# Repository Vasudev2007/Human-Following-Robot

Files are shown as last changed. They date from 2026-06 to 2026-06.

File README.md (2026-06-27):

# Autonomous Human-Following Robot

This repository is a digitalization of the course project for **TA212 (Introduction to Manufacturing Process II)** under Professor Sarvesh Mishra, completed during the 2025 Odd semester at the Indian Institute of Technology Kanpur.

An Arduino-based autonomous robot capable of tracking and following a human target. It uses an ultrasonic sensor mounted on a servo motor to gauge distance, and two infrared (IR) sensors to detect directional movement and steer the chassis.

---

## 🏆 Awards & Recognition
This project, officially titled **"Human Tracker Bot,"** was awarded the **2nd Best Project** (Tuesday Batch, Gr. No. 10) in the TA-212 Lab.

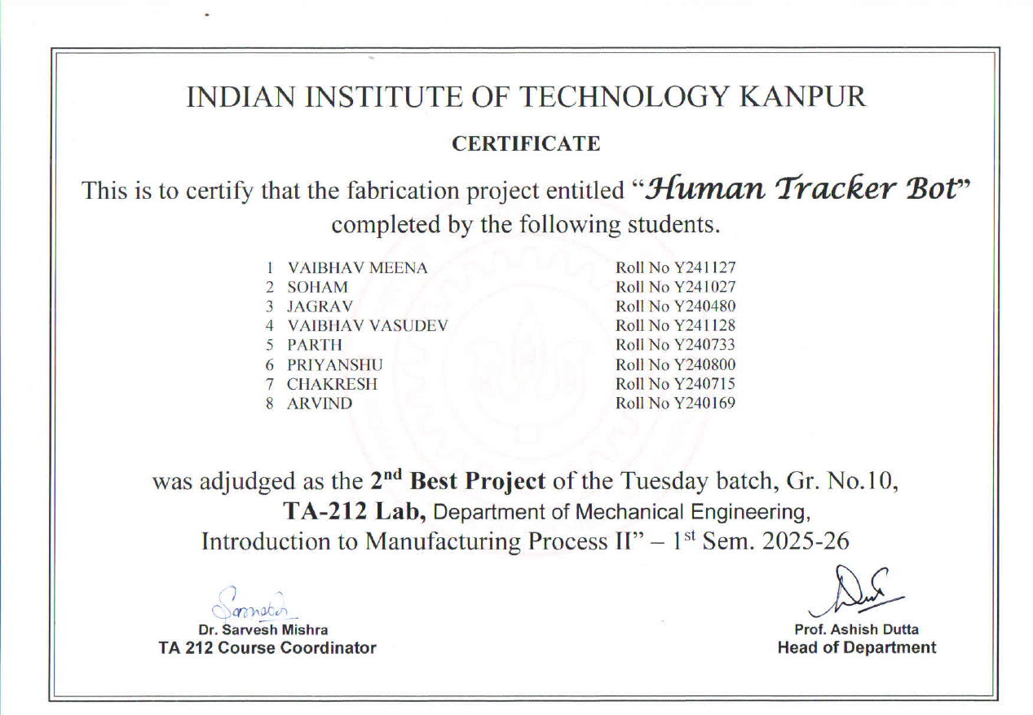
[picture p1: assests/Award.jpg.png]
TA212 2nd Best Project Certificate


---

## 🤝 Team Members
This robot was successfully fabricated and programmed through the collaborative efforts of:
* Vaibhav Meena
* Soham
* Jagrav
* Vaibhav Vasudev
* Parth
* Priyanshu
* Chakresh
* Arvind
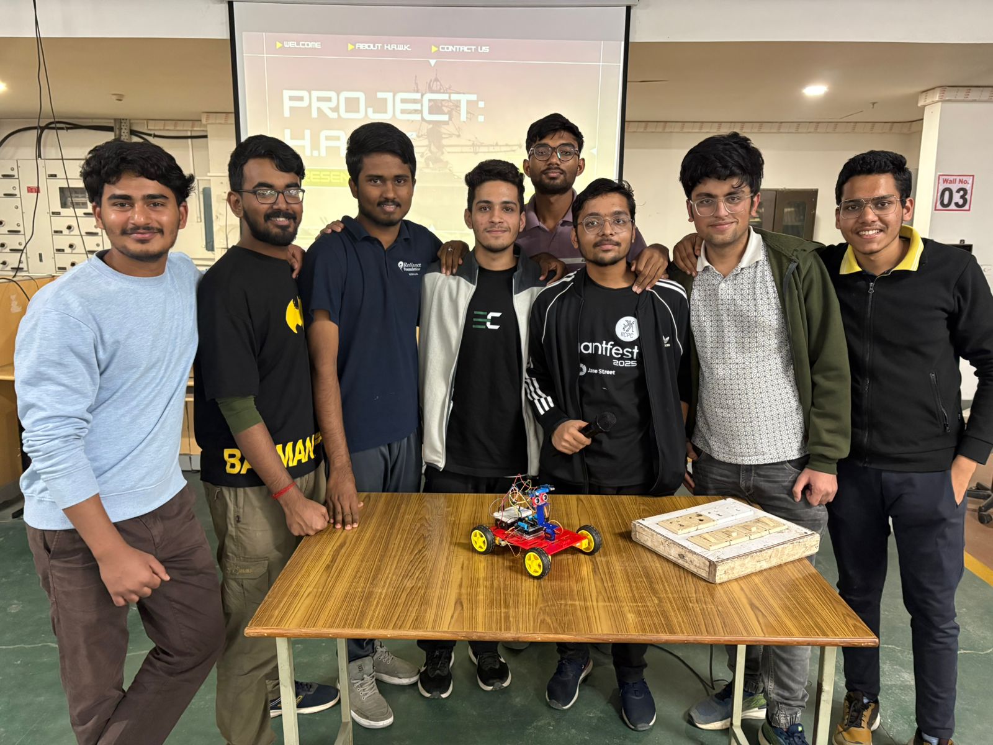
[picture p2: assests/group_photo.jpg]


---
## 🛒 Parts List & Purchase Links (Amazon.in)
1. [Arduino Uno](https://amzn.to/35flEXS)
2. [Motor Driver Shield](https://amzn.to/30Z9ijj)
3. [TT Gear Motor and wheels set](https://amzn.to/31WSD0Z)
4. [Servo Motor](https://amzn.to/2IAigNH)
5. [Ultrasonic Sensor](https://amzn.to/33fwrQa)
6. [18650 Li-on Battery (2x)](https://bit.ly/2CZabQ7)
7. [18650 Battery Holder](https://amzn.to/33iY4b3)
8. [Male and Female Jumper wire](https://amzn.to/2MmRjOE)
9. Acrylic Sheet - *(Offline Store)*
10. [DC Power Switch](https://bit.ly/2FtyEzs)

## 🛠️ Hardware Components
*   **Microcontroller:** Arduino Uno
*   **Motor Driver:** L293D Motor Driver Shield
*   **Motors:** 4x TT Gear Motors with Rubber Wheels
*   **Distance Sensor:** HC-SR04 Ultrasonic Sensor
*   **Directional Sensors:** 2x Infrared (IR) Obstacle Avoidance Sensors
*   **Actuator:** SG90 Micro Servo Motor
*   **Power:** 2x 18650 Li-ion Batteries & Battery Holder
*   **Chassis:** Custom/3D-printed base and acrylic brackets

---

## 🔌 Circuit & Wiring Connections
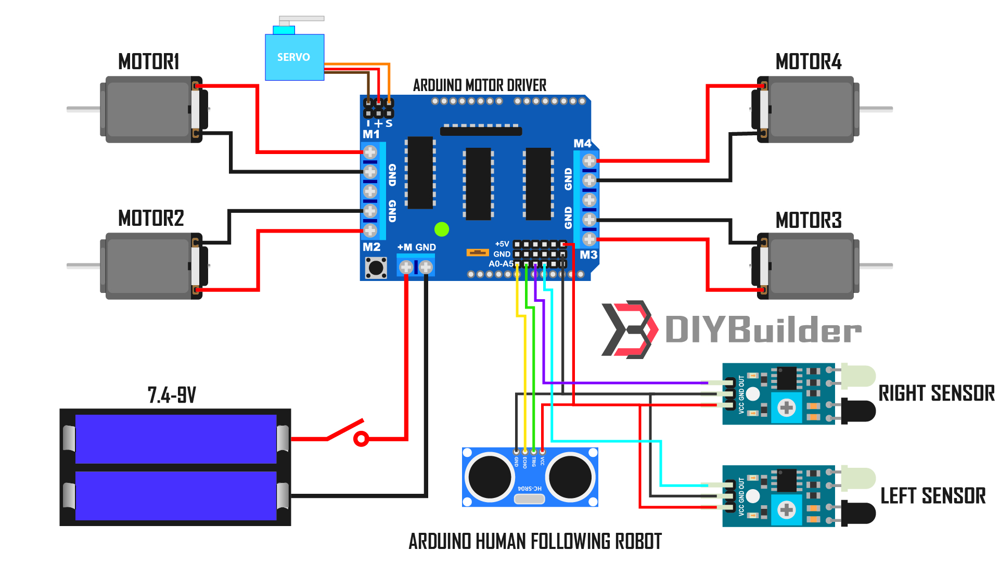
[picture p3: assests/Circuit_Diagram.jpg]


Attach the L293D Motor Shield directly on top of the Arduino Uno.

**Sensors to Motor Shield:**
*   **Right IR Sensor (OUT):** Analog Pin `A2`
*   **Left IR Sensor (OUT):** Analog Pin `A3`
*   **Ultrasonic Trigger (TRIG):** Analog Pin `A1`
*   **Ultrasonic Echo (ECHO):** Analog Pin `A0`
*   **Servo Motor (Signal):** Digital Pin `10`

*Note: Ensure all VCC pins are connected to 5V and GND pins to Ground. The motor shield requires the jumper cap on the power pins to pull power from the battery pack.*

---

## 🚀 Installation & Setup
1. Assemble the robot chassis, motors, and wire the sensors as per the connections above.
2. Install the necessary Arduino libraries via the Library Manager (`AFMotor.h`, `NewPing.h`, `Servo.h`).
3. Open `src/FollowMeRobot.ino` in the Arduino IDE.
4. Select **Arduino Uno** under `Tools > Board`.
5. Select the correct COM port under `Tools > Port`.
6. Click **Upload**.

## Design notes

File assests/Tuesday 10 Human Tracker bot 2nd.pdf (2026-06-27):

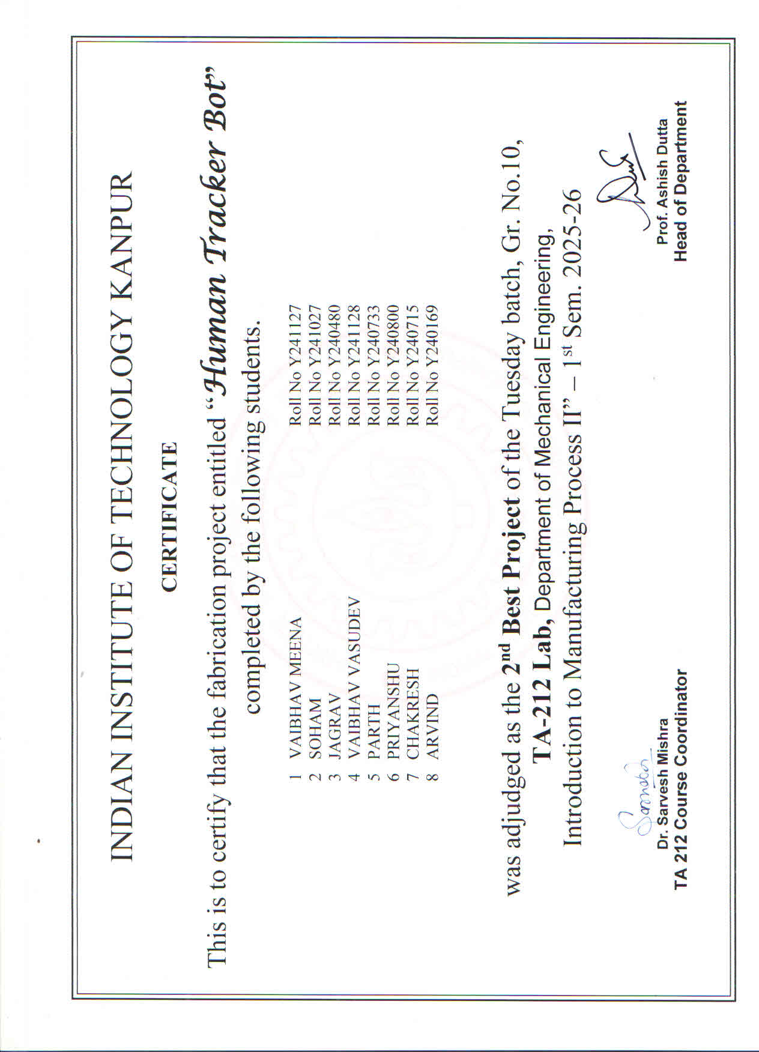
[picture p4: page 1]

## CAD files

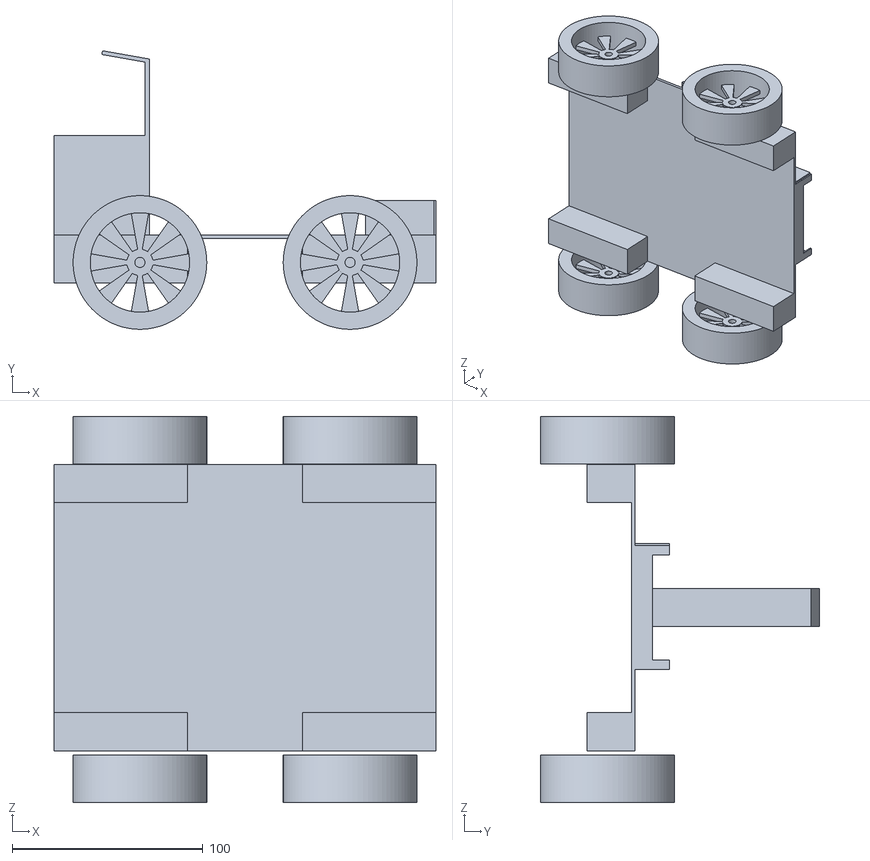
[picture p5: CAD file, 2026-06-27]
Part Drawings/Sensor holder.stl
200.0 x 145.8 x 202.2

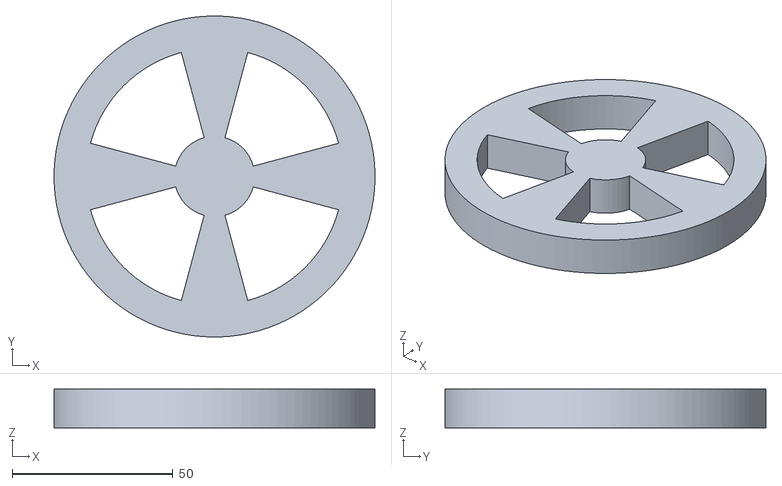
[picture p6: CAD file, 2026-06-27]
Part Drawings/Wheel New stl.stl
100.0 x 100.0 x 12.0

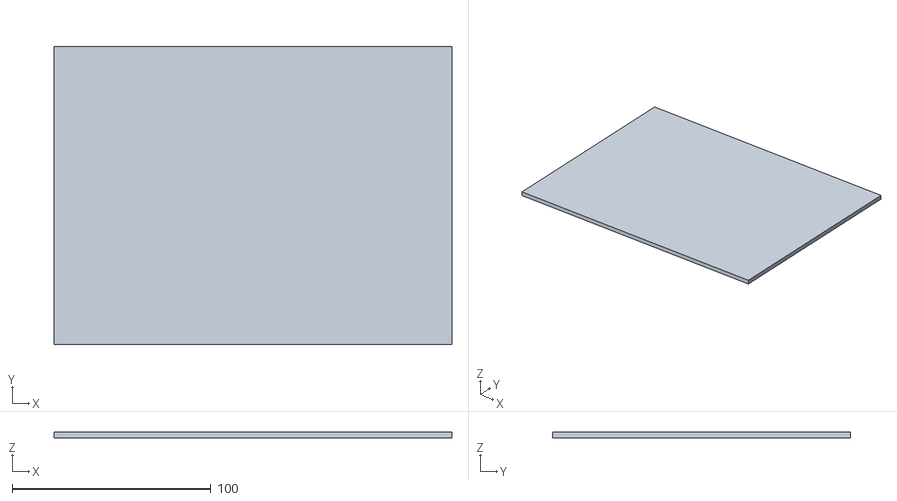
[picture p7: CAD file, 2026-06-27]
Part Drawings/base_plate.stl
200.0 x 150.0 x 3.00

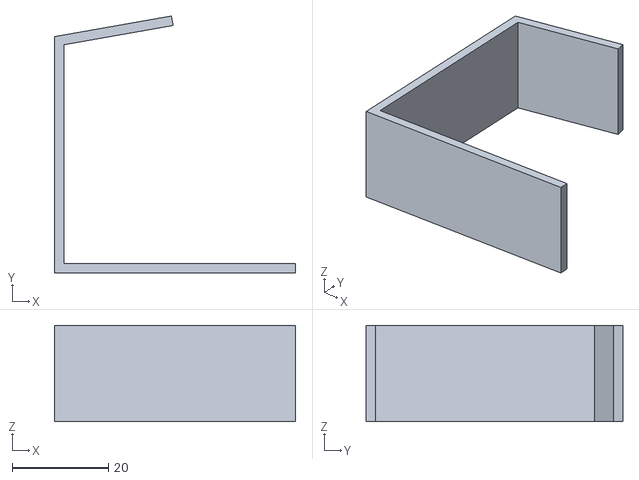
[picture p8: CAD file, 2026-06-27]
Part Drawings/Motor shaft seperate.stl
50.0 x 53.3 x 20.0

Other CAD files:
Part Drawings/Human Tracker Bot.f3d
Part Drawings/Wheel autocad new_.f3z
Part Drawings/sensor rotor final.f3d

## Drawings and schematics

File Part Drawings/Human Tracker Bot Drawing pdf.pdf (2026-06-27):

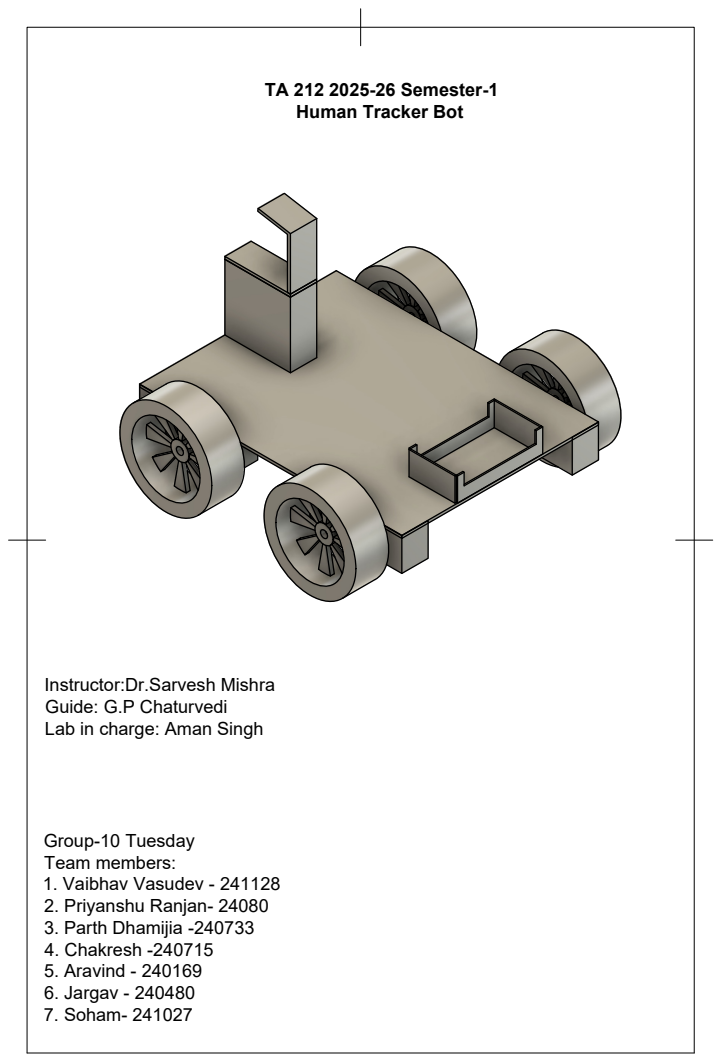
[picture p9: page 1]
Group-10 Tuesday Team members: 1. Vaibhav Vasudev - 241128 2. Priyanshu Ranjan- 24080 3. Parth Dhamijia -240733 4. Chakresh -240715 5. Aravind - 240169 6. Jargav - 240480 7. Soham- 241027

TA 212 2025-26 Semester-1
Human Tracker Bot

Instructor:Dr.Sarvesh Mishra
Guide: G.P Chaturvedi
Lab in charge: Aman Singh

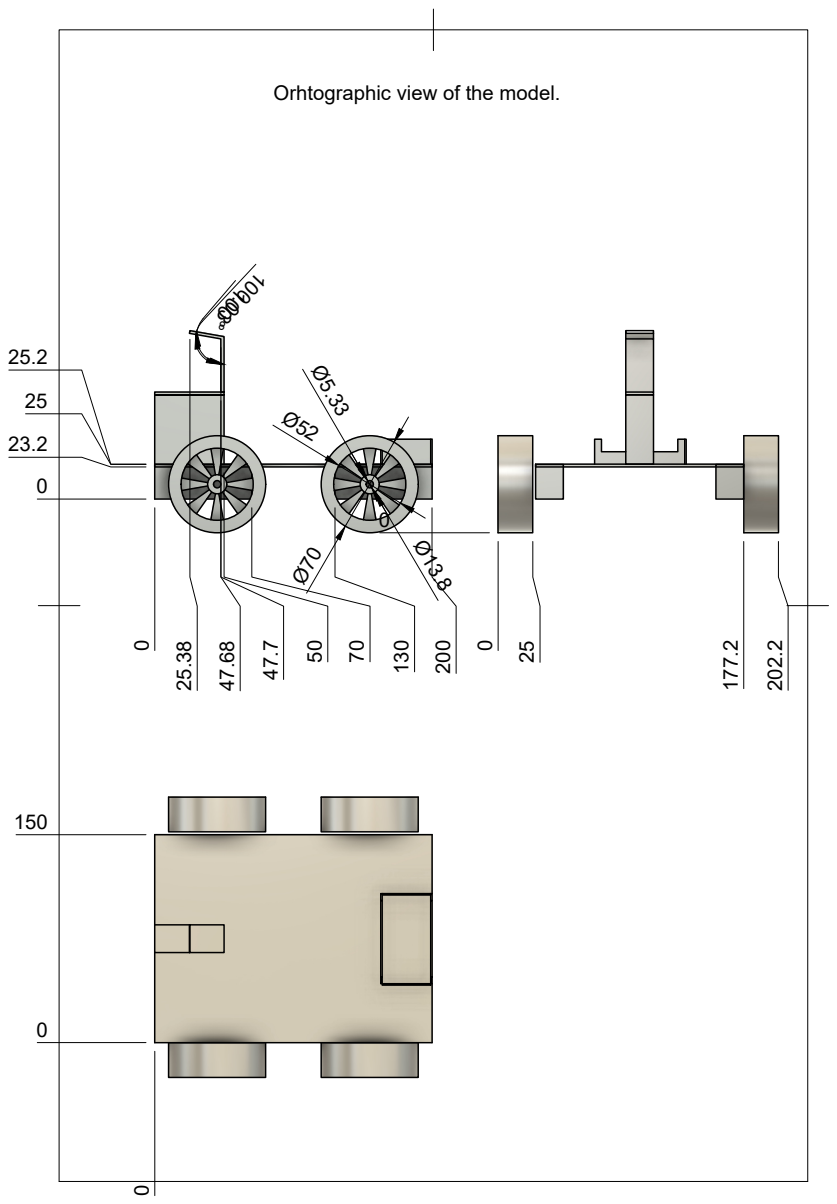
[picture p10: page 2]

Orhtographic view of the model.

Materials Required List

Parts to be required

Sr.no | Parts name | Dimensions | Materials Required | Qty
1 | Base Plate | 200*150*2 | Mild Steel | 4
2 | Wheel Outer Disc | " | Φ70*250" | 3D Print
3 | Wheel Inner Disc | Φ13.8*3.6 | 3D Print | 4
4 | Wheel Spokes dimensions | 3* 20 deg spread | 3D Print | 4
5 | Sensor Rotor | 50*20*96.34 | 3D Print | 1

All dimensions are in mm.

Sr.no | Part name | Technical details | Qty
1 | Ardurino Uno | Geekcreit® UNO R3 ATmega16U2 AVR USB Development Main Board Geekcreit for Arduino - products that work with official Arduino boards
1
2 | Ardurino Motor Drive Shield
Generic
0826U40KLRA Q
L293D Motor
Driver/Stepper/Ser
vo Shield for
Arduino

1

3 | TT Gear Motor | Robotbanao Combo-100RPM Dual Shaft BO Motor With 65mm Robot Wheel-Reinforced Rubber Wheel-Geared DC Motor-Smart Car Robot Geared Motor-Black And Yellow-Pack Of 4
4
4 | Servo Motor | TowerPro SG 90 Micro Servo Motor
5 | Ultrasonic Sensor | REES52 Ultrasonic Range Finder Module Sensor Distance Measuring Transducer New
1
6 | 18650 Li-on Battery

2

7 | 18650 Battery Holder
1
8 | Male and Female Jumper Wire

1

9 | hc-05 Bluetooth module

1

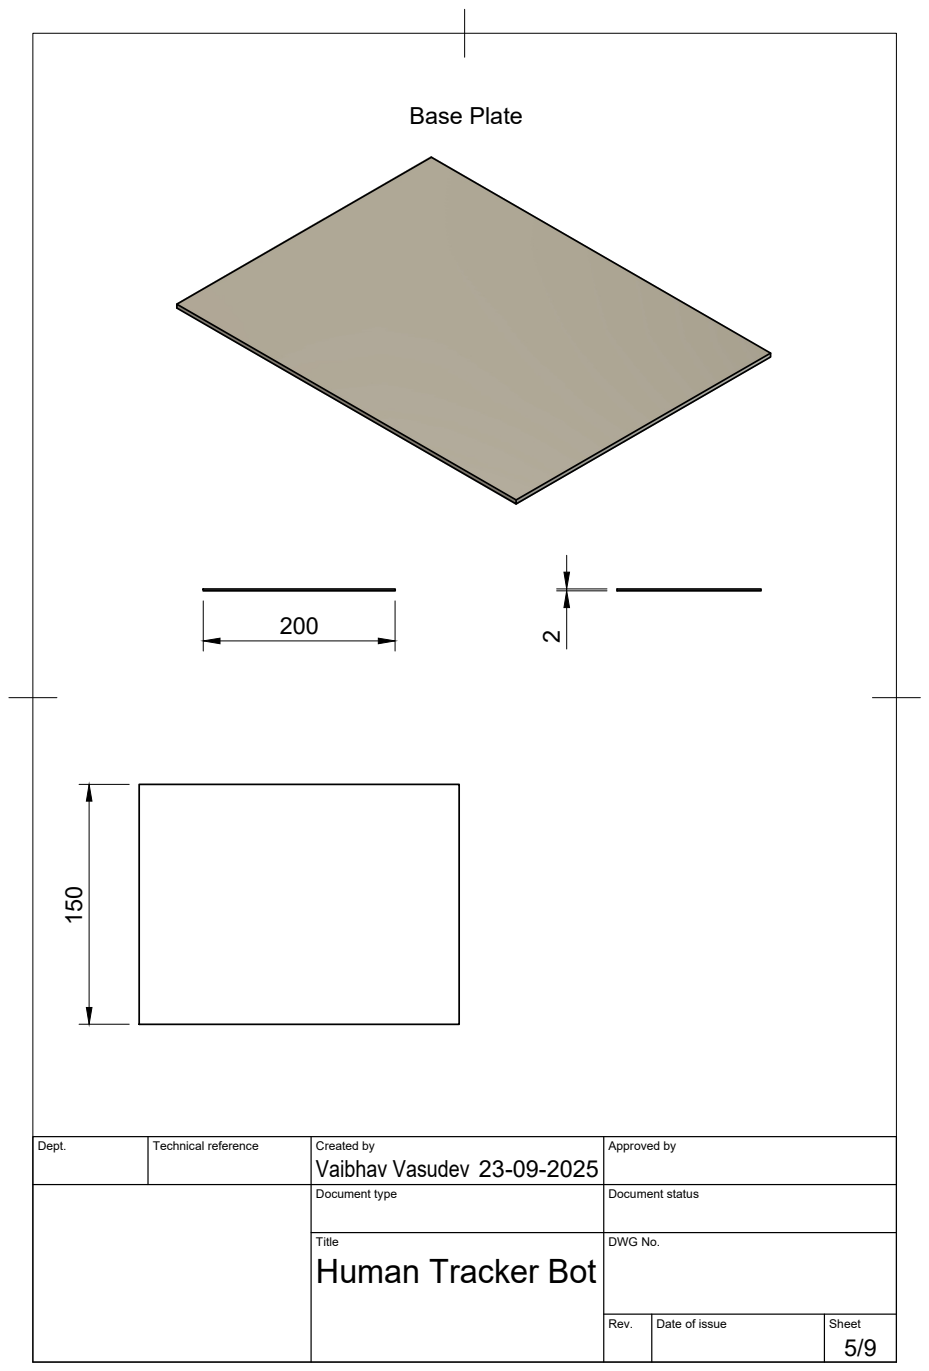
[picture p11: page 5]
Base Plate

Dept. | Technical reference | Created by Vaibhav Vasudev 23-09-2025 | Approved by

Document type | Document status

Title Human Tracker Bot | DWG No.

Rev. | Date of issue | Sheet

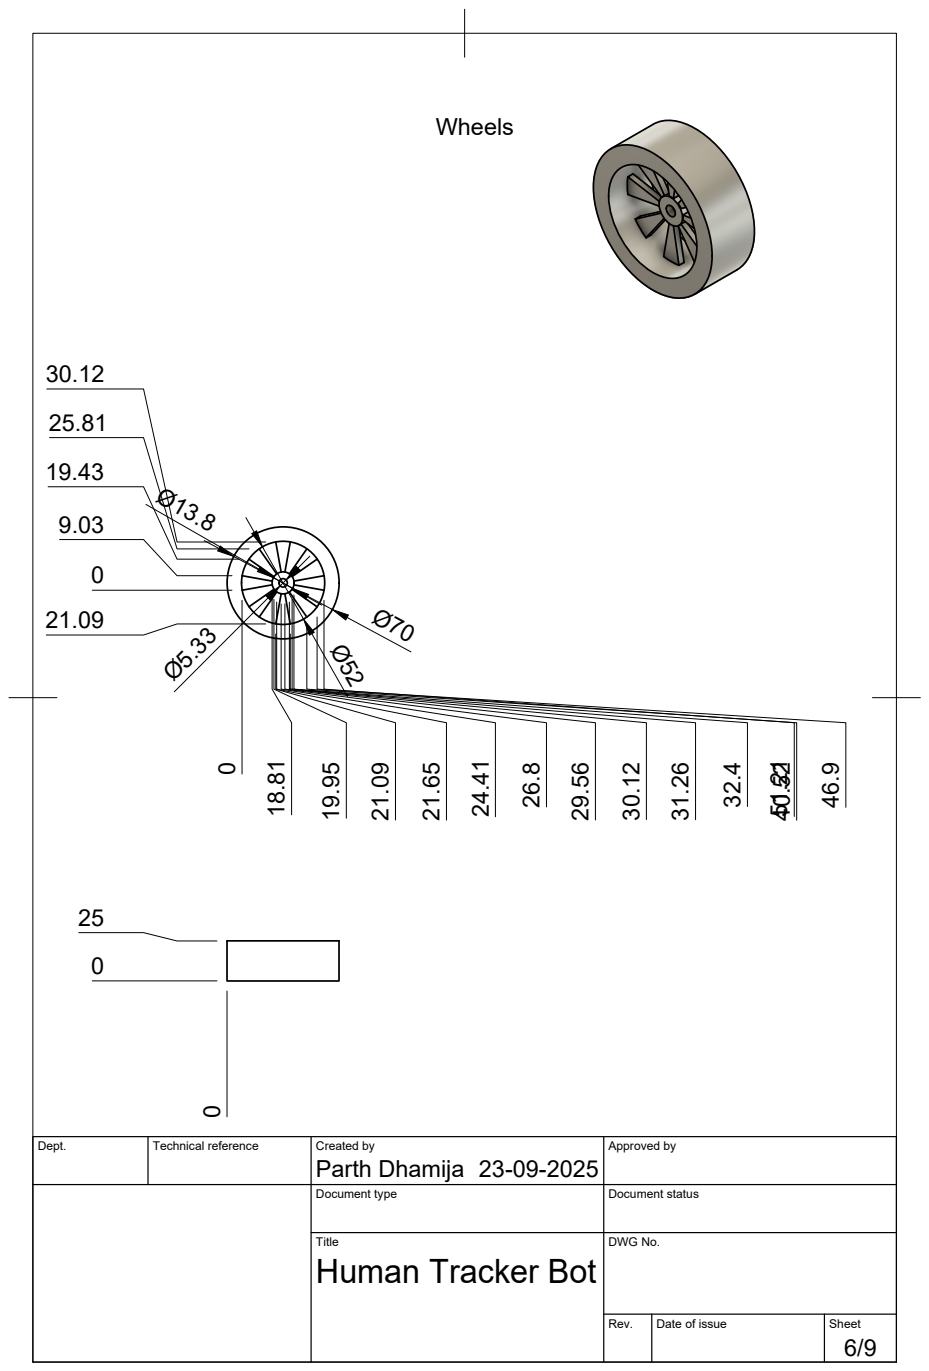
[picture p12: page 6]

Dept. | Technical reference | Created by Parth Dhamija 23-09-2025 | Approved by

Document type | Document status

Title Human Tracker Bot | DWG No.

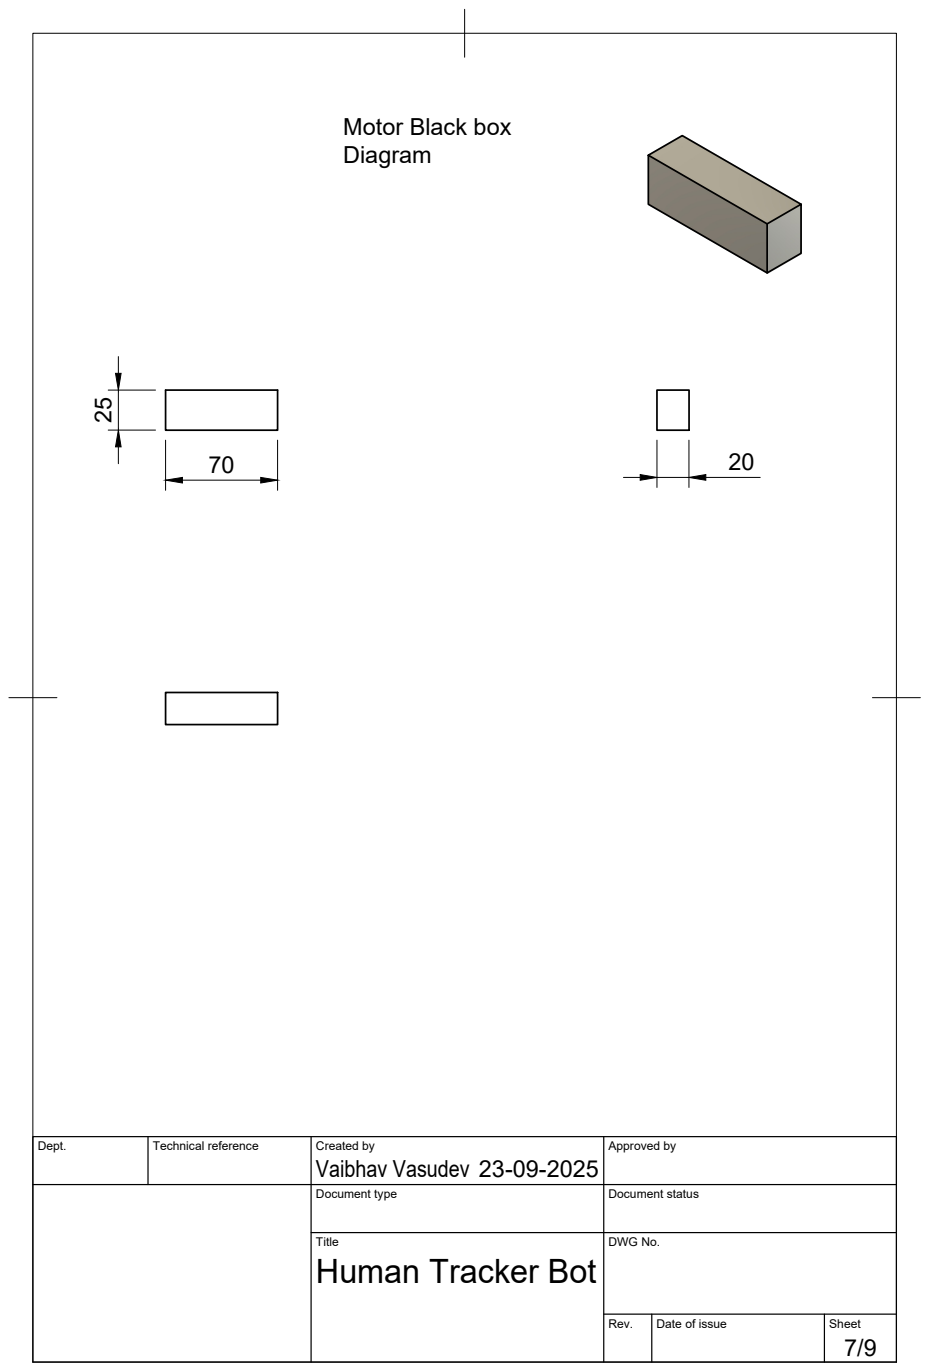
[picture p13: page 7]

Motor Black box
Diagram

Dept. | Technical reference | Created by Vaibhav Vasudev 23-09-2025 | Approved by

Document type | Document status

Title Human Tracker Bot | DWG No.

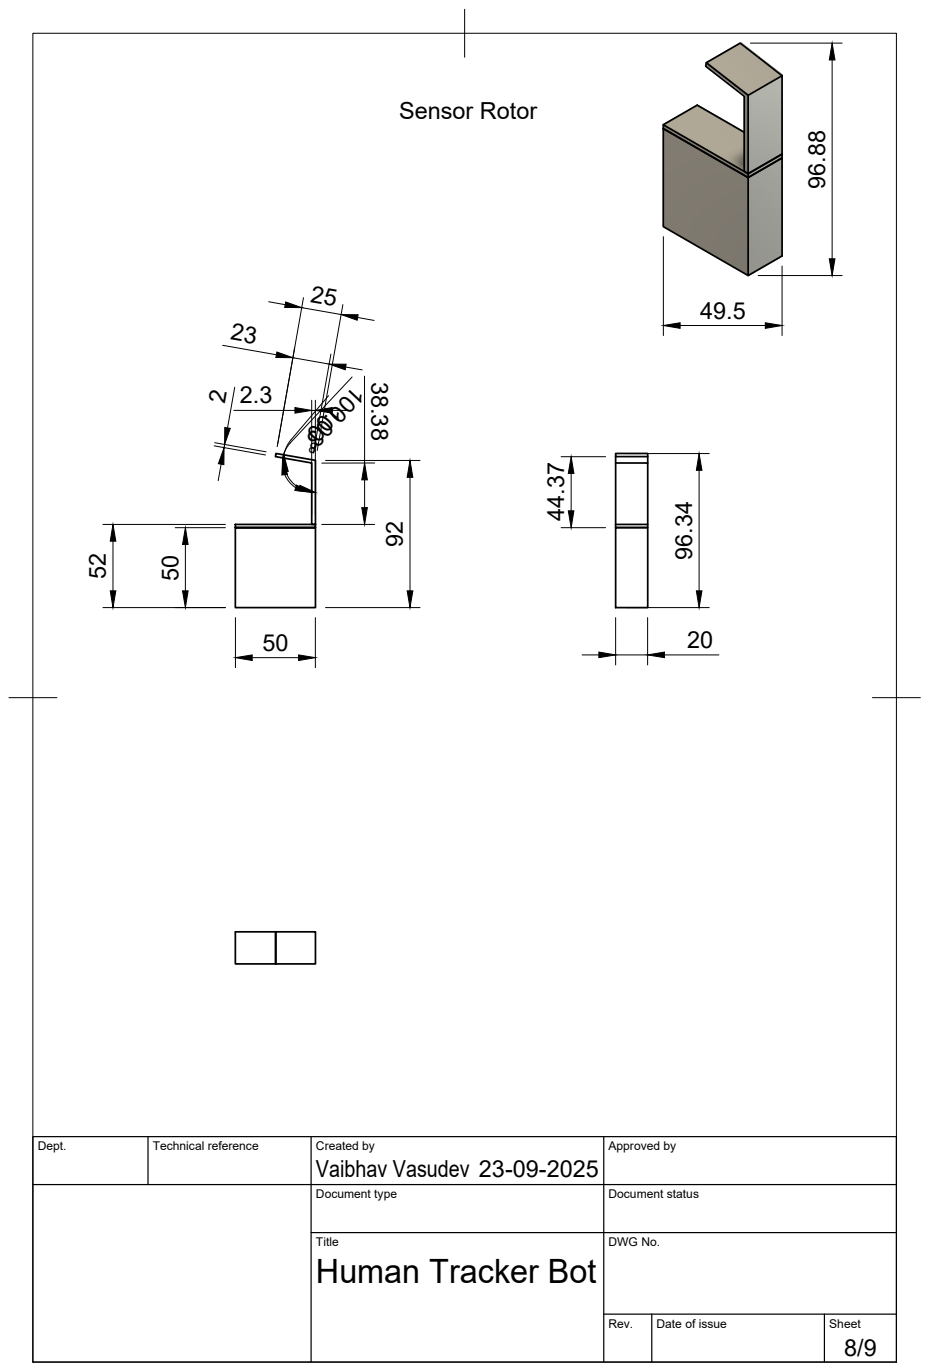
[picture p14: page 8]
Sensor Rotor

Dept. | Technical reference | Created by Vaibhav Vasudev 23-09-2025 | Approved by

Document type | Document status

Title Human Tracker Bot | DWG No.

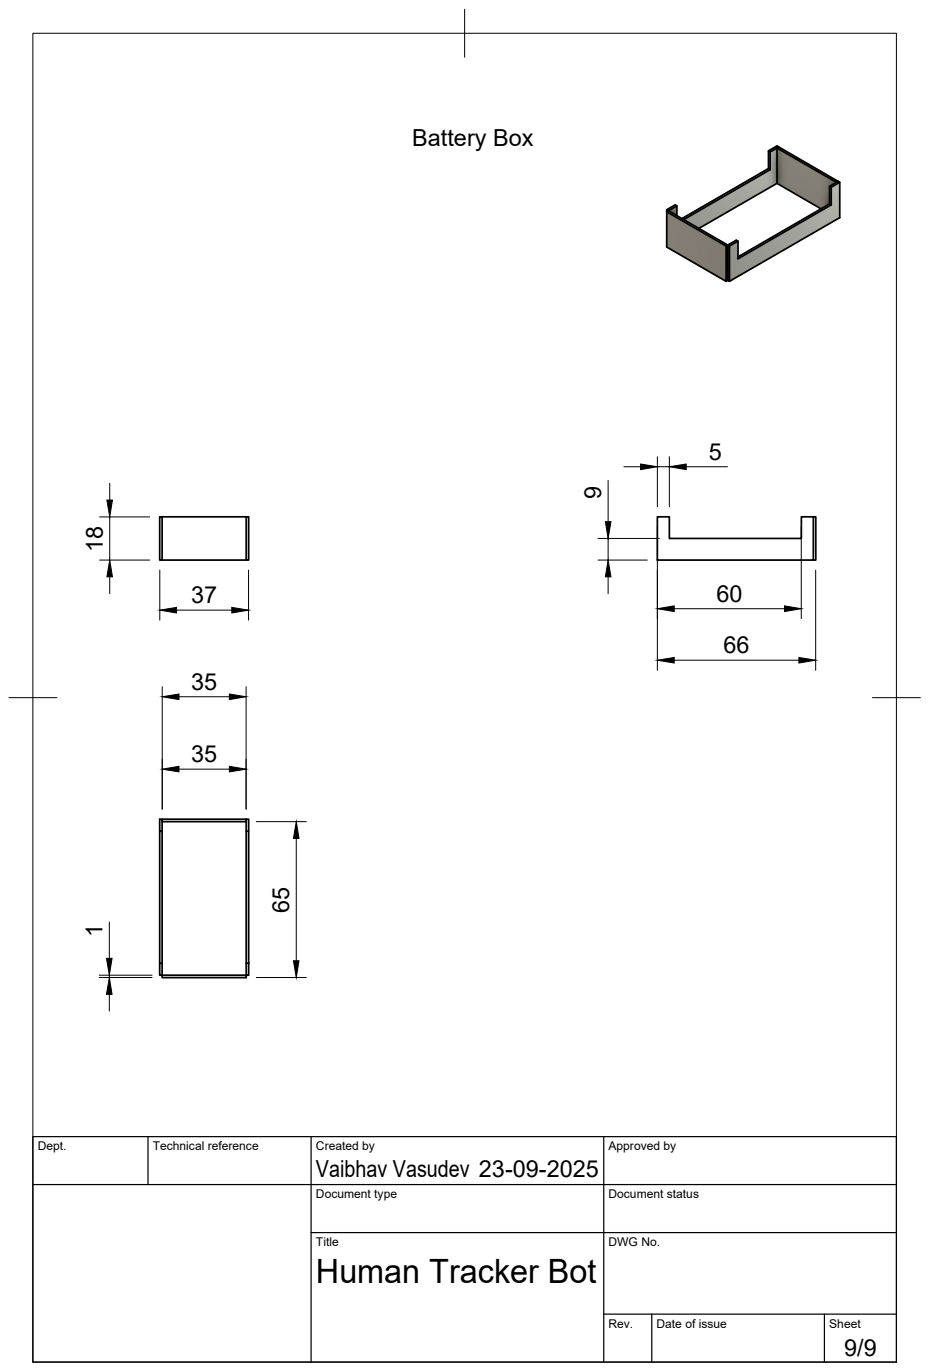
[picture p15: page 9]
Battery Box

Dept. | Technical reference | Created by Vaibhav Vasudev 23-09-2025 | Approved by

Document type | Document status

Title Human Tracker Bot | DWG No.

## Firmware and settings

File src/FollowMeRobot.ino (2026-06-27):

#include <AFMotor.h>
#include <NewPing.h>
#include <Servo.h>

// Sensor Pins
#define RIGHT A2
#define LEFT A3
#define TRIGGER_PIN A1
#define ECHO_PIN A0
#define MAX_DISTANCE 100

// Initialize Ultrasonic Sensor
NewPing sonar(TRIGGER_PIN, ECHO_PIN, MAX_DISTANCE);

// Initialize Motors via L293D Shield
AF_DCMotor Motor1(1, MOTOR12_1KHZ);
AF_DCMotor Motor2(2, MOTOR12_1KHZ);
AF_DCMotor Motor3(3, MOTOR34_1KHZ);
AF_DCMotor Motor4(4, MOTOR34_1KHZ);

Servo myservo;
int pos = 0;

void setup() {
  Serial.begin(9600);
  
  // Attach Servo to pin 10
  myservo.attach(10);
  
  // Servo Initialization Sweep (Look Left to Right)
  for(pos = 90; pos <= 180; pos += 1) {
    myservo.write(pos);
    delay(15);
  }
  for(pos = 180; pos >= 0; pos -= 1) {
    myservo.write(pos);
    delay(15);
  }
  for(pos = 0; pos <= 90; pos += 1) {
    myservo.write(pos);
    delay(15);
  }
  
  // Set IR pins as inputs
  pinMode(RIGHT, INPUT);
  pinMode(LEFT, INPUT);
}

void loop() {
  delay(50);
  
  // Read distance from Ultrasonic Sensor
  unsigned int distance = sonar.ping_cm();
  
  // Read values from IR Sensors
  int Right_Value = digitalRead(RIGHT);
  int Left_Value = digitalRead(LEFT);

  // --- Following Logic ---
  
  // Target is straight ahead
  if((Right_Value == 1) && (Left_Value == 1)) {
    if(distance > 1 && distance < 15) {
      // Too close, stop moving
      stopRobot();
    } else if(distance >= 15 && distance <= 35) {
      // Target in range, move forward
      moveForward();
    }
  } 
  // Target is drifting to the Right
  else if((Right_Value == 0) && (Left_Value == 1)) {
    turnRight();
  } 
  // Target is drifting to the Left
  else if((Right_Value == 1) && (Left_Value == 0)) {
    turnLeft();
  } 
  // Target is lost or completely out of bounds
  else if((Right_Value == 0) && (Left_Value == 0)) {
    stopRobot();
  }
}

// --- Movement Helper Functions ---

void moveForward() {
  Motor1.setSpeed(150); Motor1.run(FORWARD);
  Motor2.setSpeed(150); Motor2.run(FORWARD);
  Motor3.setSpeed(150); Motor3.run(FORWARD);
  Motor4.setSpeed(150); Motor4.run(FORWARD);
}

void turnRight() {
  Motor1.setSpeed(150); Motor1.run(FORWARD);
  Motor2.setSpeed(150); Motor2.run(FORWARD);
  Motor3.setSpeed(150); Motor3.run(BACKWARD);
  Motor4.setSpeed(150); Motor4.run(BACKWARD);
}

void turnLeft() {
  Motor1.setSpeed(150); Motor1.run(BACKWARD);
  Motor2.setSpeed(150); Motor2.run(BACKWARD);
  Motor3.setSpeed(150); Motor3.run(FORWARD);
  Motor4.setSpeed(150); Motor4.run(FORWARD);
}

void stopRobot() {
  Motor1.setSpeed(0); Motor1.run(RELEASE);
  Motor2.setSpeed(0); Motor2.run(RELEASE);
  Motor3.setSpeed(0); Motor3.run(RELEASE);
  Motor4.setSpeed(0); Motor4.run(RELEASE);
}

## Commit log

2026-06-27 Add robot control code with ultrasonic and IR sensors
2026-06-27 Rename ARDUINO HUMAN FOLLOWING CAR1.jpg to Circuit_Diagram.jpg
